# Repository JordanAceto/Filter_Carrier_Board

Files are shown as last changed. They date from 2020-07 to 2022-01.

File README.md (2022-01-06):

# PCB carrier board for VCF plug-in boards.



## [SCHEMATIC](https://github.com/JordanAceto/Filter_Carrier_Board/blob/master/main_pcb/construction_docs/filter_carrier_schematic.pdf)

### This PCB is designed to accomodate various filter boards documented elsewhere on my github page. Pots and jacks are mounted on this board, which can be affixed to a Eurorack panel. This way you can have one carrier board/panel, and swap in various VCF designs.

### A 12hp pcb panel is included in this repo as a cheap panel option.

### Since the panal and panel-mount components are typically a large expense in a synth module, this allows you to evaluate and experiment with different filter designs economically.

### Various plug-in boards have already been designed as part of a different project, and this seemed like an easy way to leverage an existing design in order to mess around with a Eurorack setup.

### Here is a link to the repository of the plug-in boards: [LINK](https://github.com/JordanAceto/VCF_plug_in_boards "filter plug-in boards")

## Status of the project:

Task | Status |
---------|--------------|
Schematic capture | &#9745;
PCB layout | &#9745;
Test build | &#9745;
Safe to order boards| &#9745;

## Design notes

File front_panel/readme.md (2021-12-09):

# Cheap and cheerful front panel option

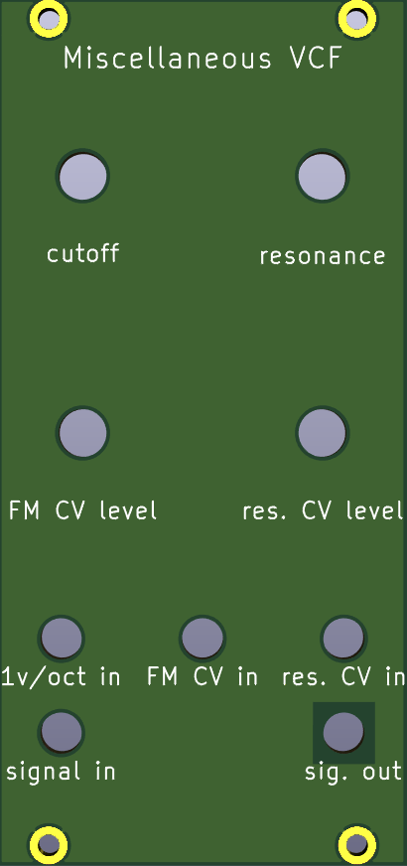
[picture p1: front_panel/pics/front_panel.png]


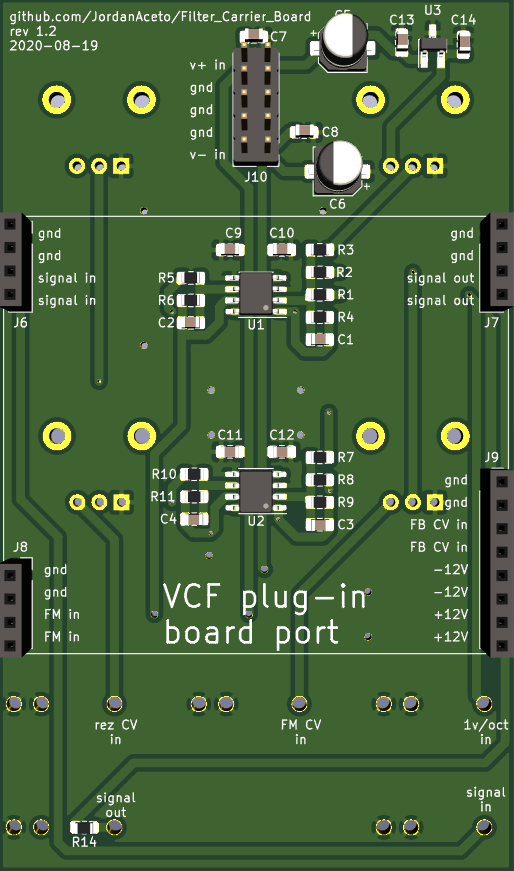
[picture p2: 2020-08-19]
main_pcb/pics/pcb_rear.png

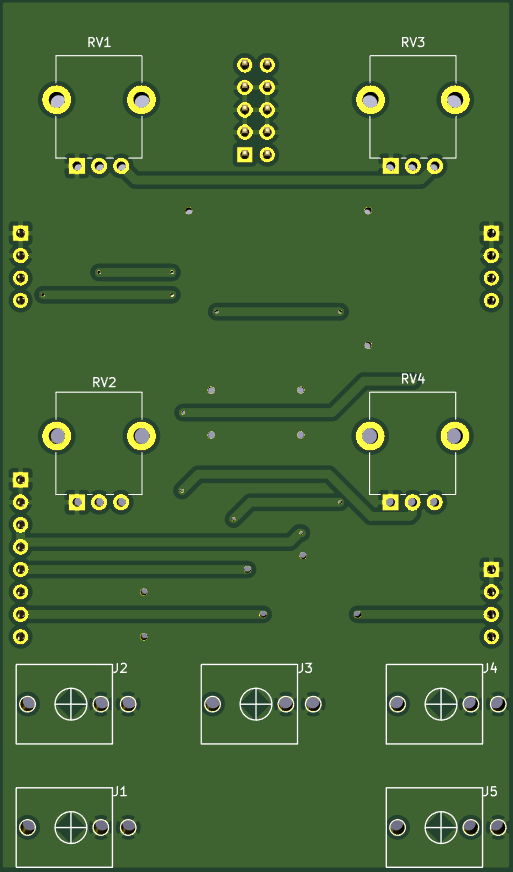
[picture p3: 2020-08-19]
main_pcb/pics/pcb_front.png

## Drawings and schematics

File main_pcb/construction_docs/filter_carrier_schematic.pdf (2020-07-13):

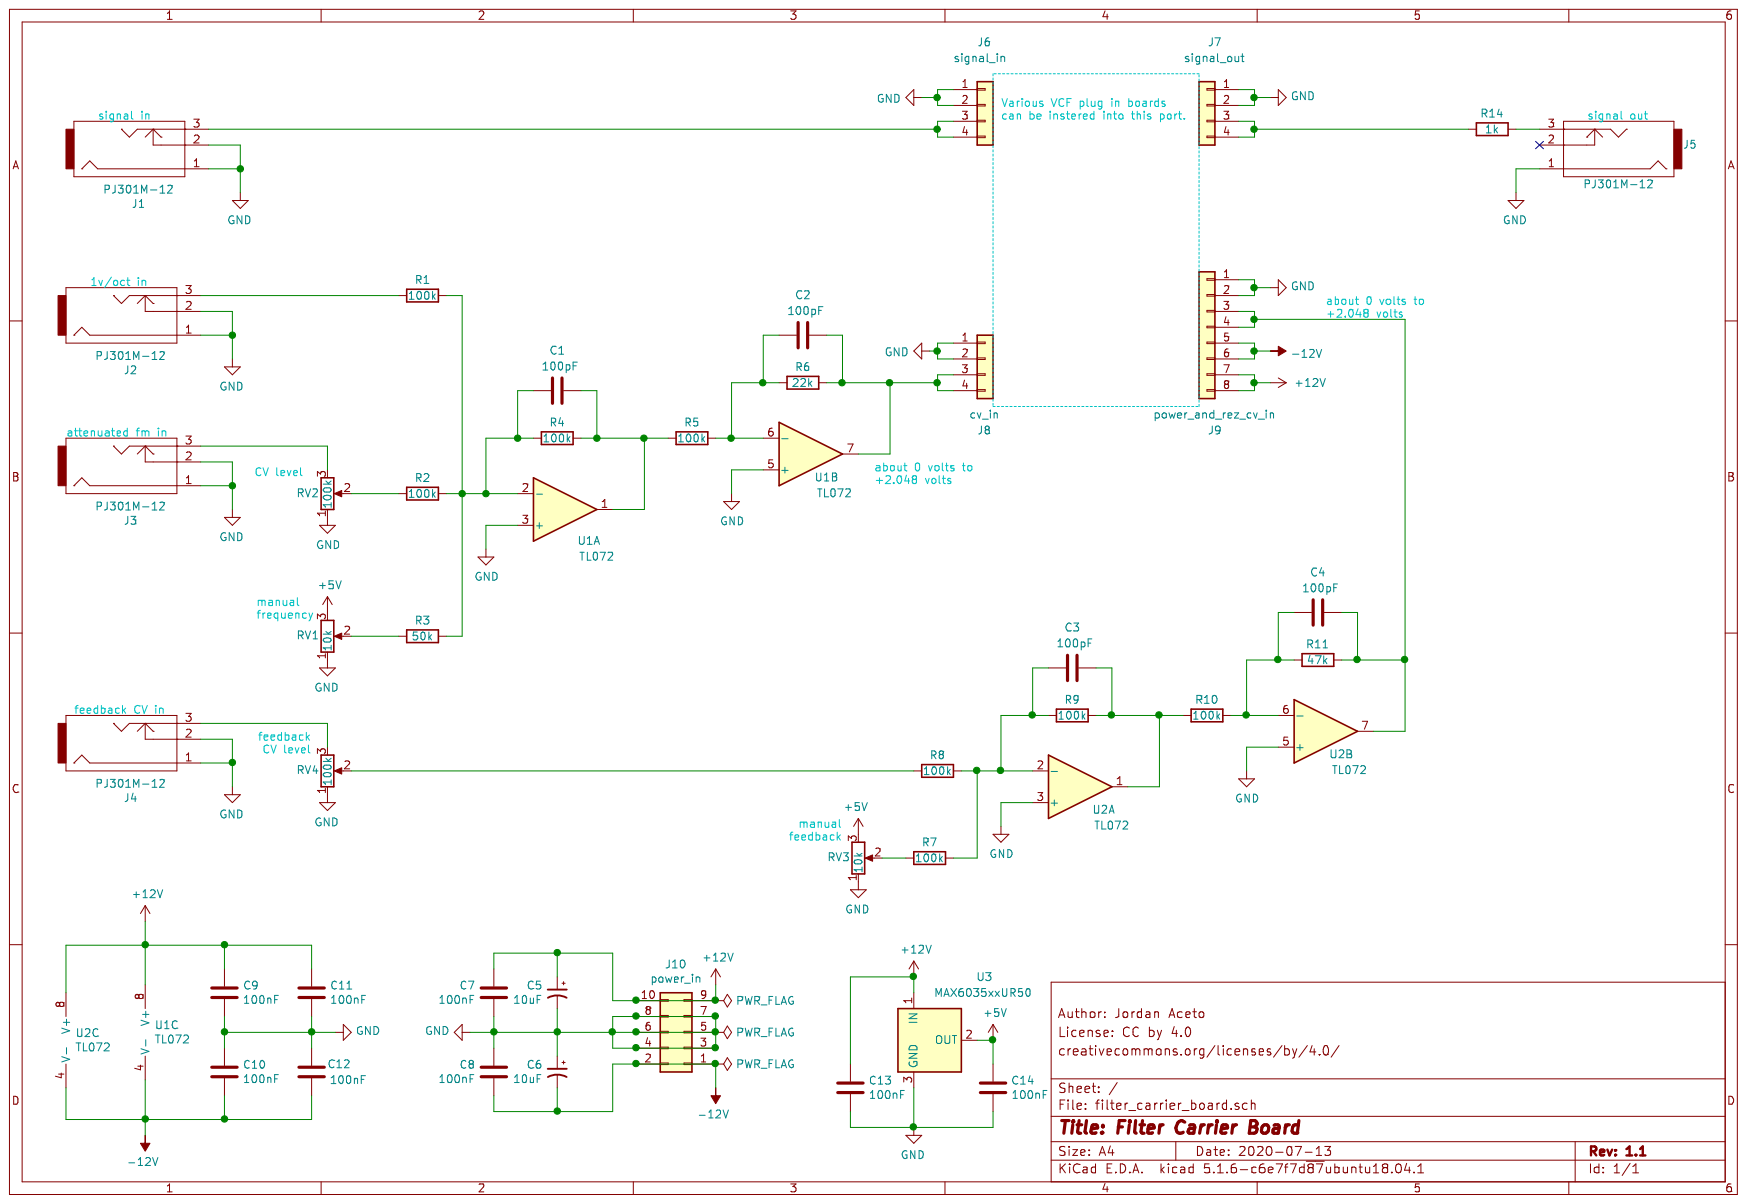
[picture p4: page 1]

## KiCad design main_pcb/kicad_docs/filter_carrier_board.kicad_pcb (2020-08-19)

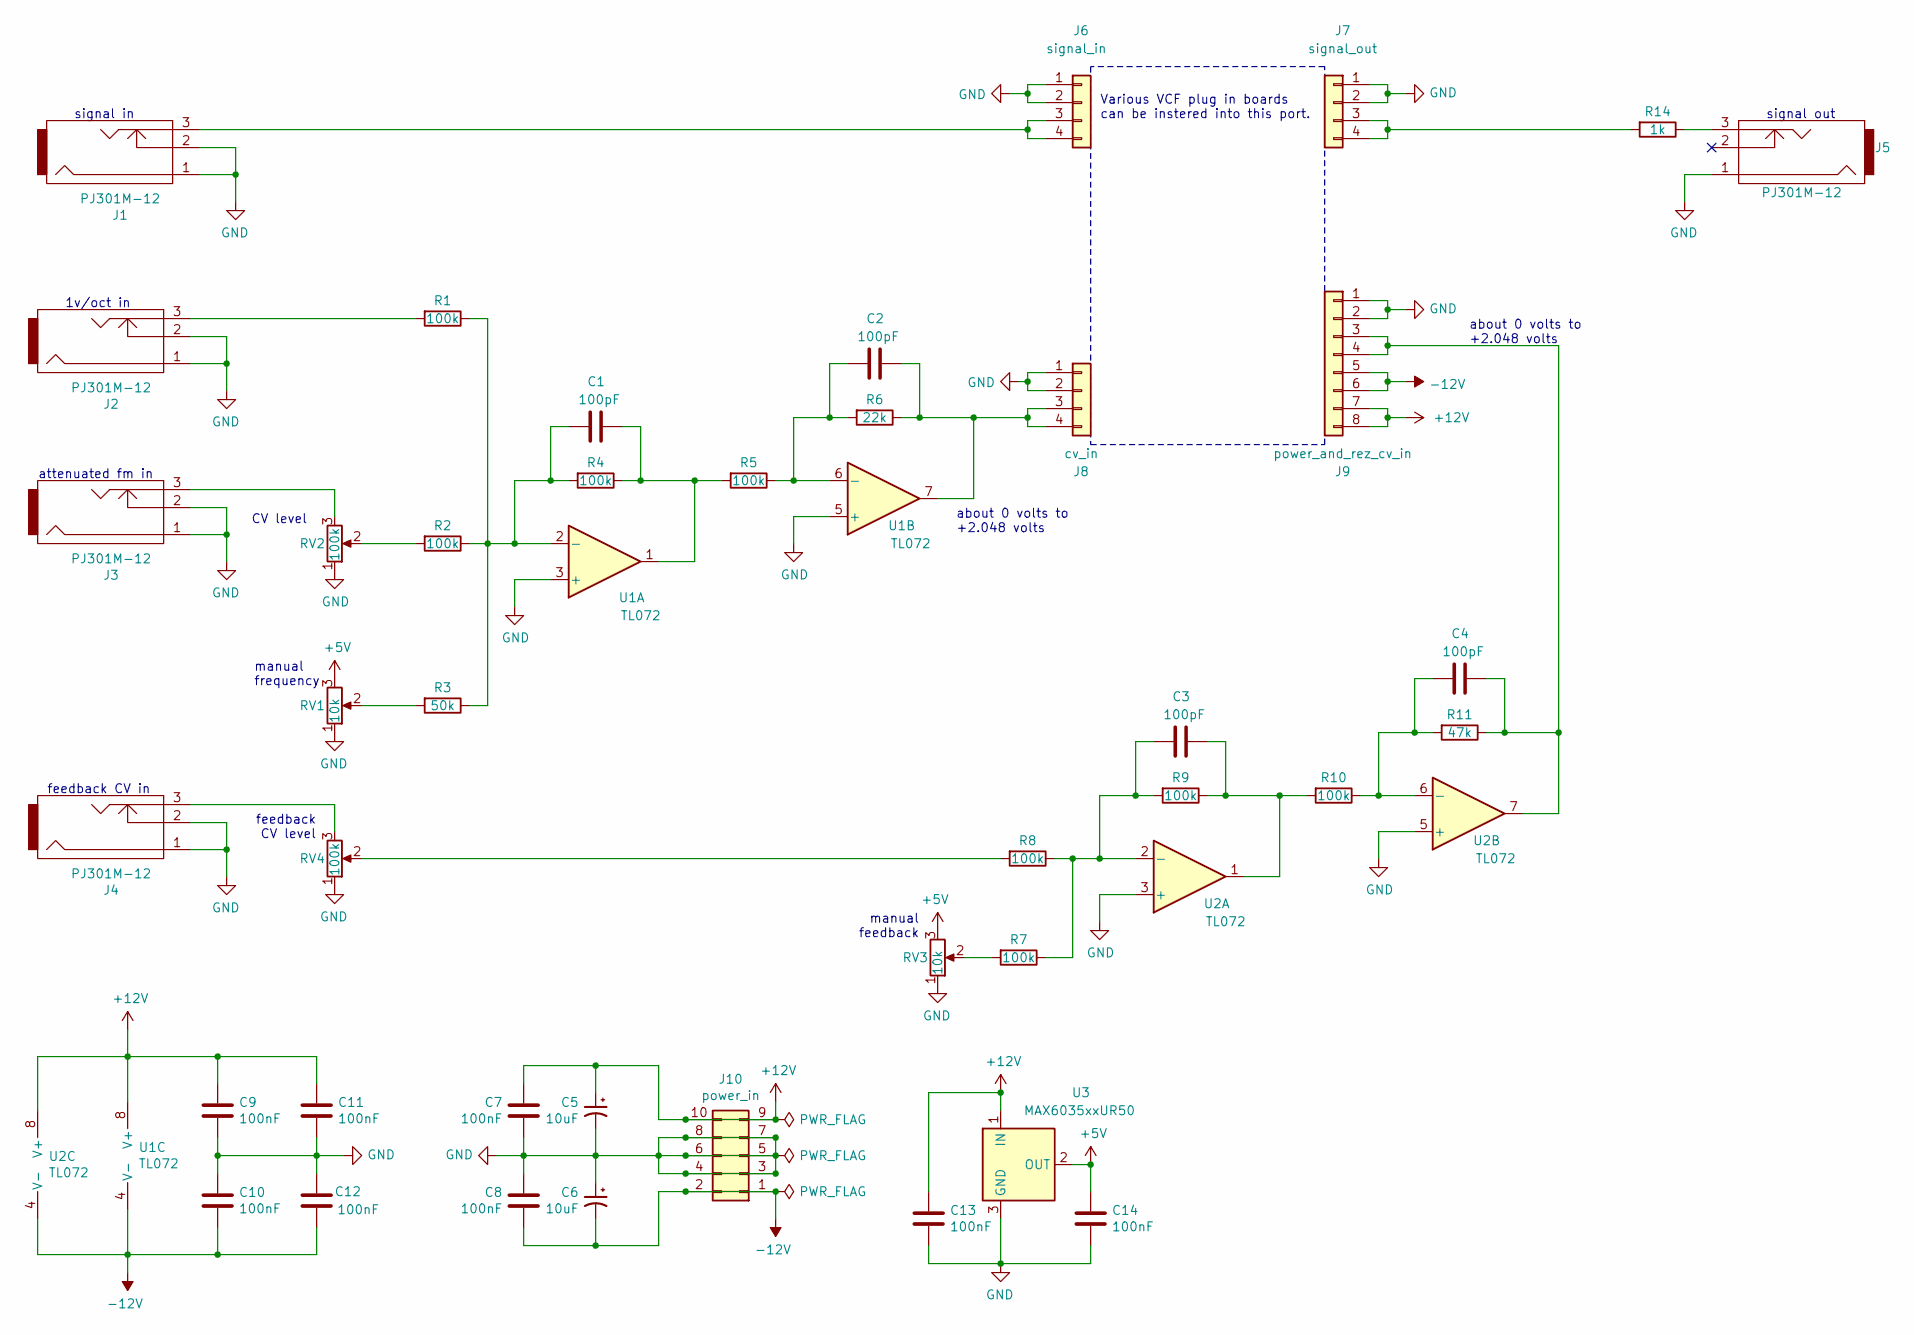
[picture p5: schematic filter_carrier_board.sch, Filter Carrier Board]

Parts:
C1, C2, C3, C4: 100pF; C_0805_2012Metric_Pad1.15x1.40mm_HandSolder
C5, C6: 10uF; CP_Elec_5x5.4
C7, C8, C9, C10, C11, C12, C13, C14: 100nF; C_0805_2012Metric_Pad1.15x1.40mm_HandSolder
J1, J2, J3, J4, J5: PJ301M-12
J6: signal_in; PinSocket_1x04_P2.54mm_Vertical
J7: signal_out; PinSocket_1x04_P2.54mm_Vertical
J8: cv_in; PinSocket_1x04_P2.54mm_Vertical
J9: power_and_rez_cv_in; PinSocket_1x08_P2.54mm_Vertical
J10: power_in; PinHeader_2x05_P2.54mm_Vertical
R1, R2, R4, R5, R7, R8, R9, R10: 100k; R_0805_2012Metric_Pad1.15x1.40mm_HandSolder
R3: 50k; R_0805_2012Metric_Pad1.15x1.40mm_HandSolder
R6: 22k; R_0805_2012Metric_Pad1.15x1.40mm_HandSolder
R11: 47k; R_0805_2012Metric_Pad1.15x1.40mm_HandSolder
R14: 1k; R_0805_2012Metric_Pad1.15x1.40mm_HandSolder
RV1, RV3: 10k; Potentiometer_Alpha_RD901F-40-00D_Single_Vertical_CircularH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
RV2, RV4: 100k; Potentiometer_Alpha_RD901F-40-00D_Single_Vertical_CircularH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
U1, U2: TL072; SOIC-8_3.9x4.9mm_P1.27mm
U3: MAX6035xxUR50; SOT-23_Handsoldering

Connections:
+5V: C14.1, RV1.3, RV3.3, U3.2 (OUT)
+12V: C5.1, C7.1, C9.1, C11.1, C13.1, J9.7, J9.8, J10.9, J10.10, U1.8 (V+), U2.8 (V+), U3.1 (IN)
-12V: C6.2, C8.2, C10.2, C12.2, J9.5, J9.6, J10.1, J10.2, U1.4 (V-), U2.4 (V-)
GND: C5.2, C6.1, C7.2, C8.1, C9.2, C10.1, C11.2, C12.1, C13.2, C14.2, J1.1, J1.2, J2.1, J2.2, J3.1, J3.2, J4.1, J4.2, J5.1, J6.1, J6.2, J7.1, J7.2, J8.1, J8.2, J9.1, J9.2, J10.3, J10.4, J10.5, J10.6, J10.7, J10.8, RV1.1, RV2.1, RV3.1, RV4.1, U1.3 (+), U1.5 (+), U2.3 (+), U2.5 (+), U3.3 (GND)
unnamed: C1.1, R4.1, R5.2, U1.1
unnamed: C1.2, R1.1, R2.1, R3.1, R4.2, U1.2 (-)
unnamed: C2.1, J8.3, J8.4, R6.1, U1.7
unnamed: C2.2, R5.1, R6.2, U1.6 (-)
unnamed: C3.1, R9.1, R10.2, U2.1
unnamed: C3.2, R7.1, R8.1, R9.2, U2.2 (-)
unnamed: C4.1, J9.3, J9.4, R11.1, U2.7
unnamed: C4.2, R10.1, R11.2, U2.6 (-)
unnamed: J1.3, J6.3, J6.4
unnamed: J2.3, R1.2
unnamed: J3.3, RV2.3
unnamed: J4.3, RV4.3
unnamed: J5.3, R14.1
unnamed: J7.3, J7.4, R14.2
unnamed: R2.2, RV2.2
unnamed: R3.2, RV1.2
unnamed: R7.2, RV3.2
unnamed: R8.2, RV4.2

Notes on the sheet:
manual frequency
1v/oct in
attenuated fm in
signal in
signal out
manual feedback
Various VCF plug in boards can be instered into this port.
feedback CV level
feedback CV in
CV level
about 0 volts to +2.048 volts

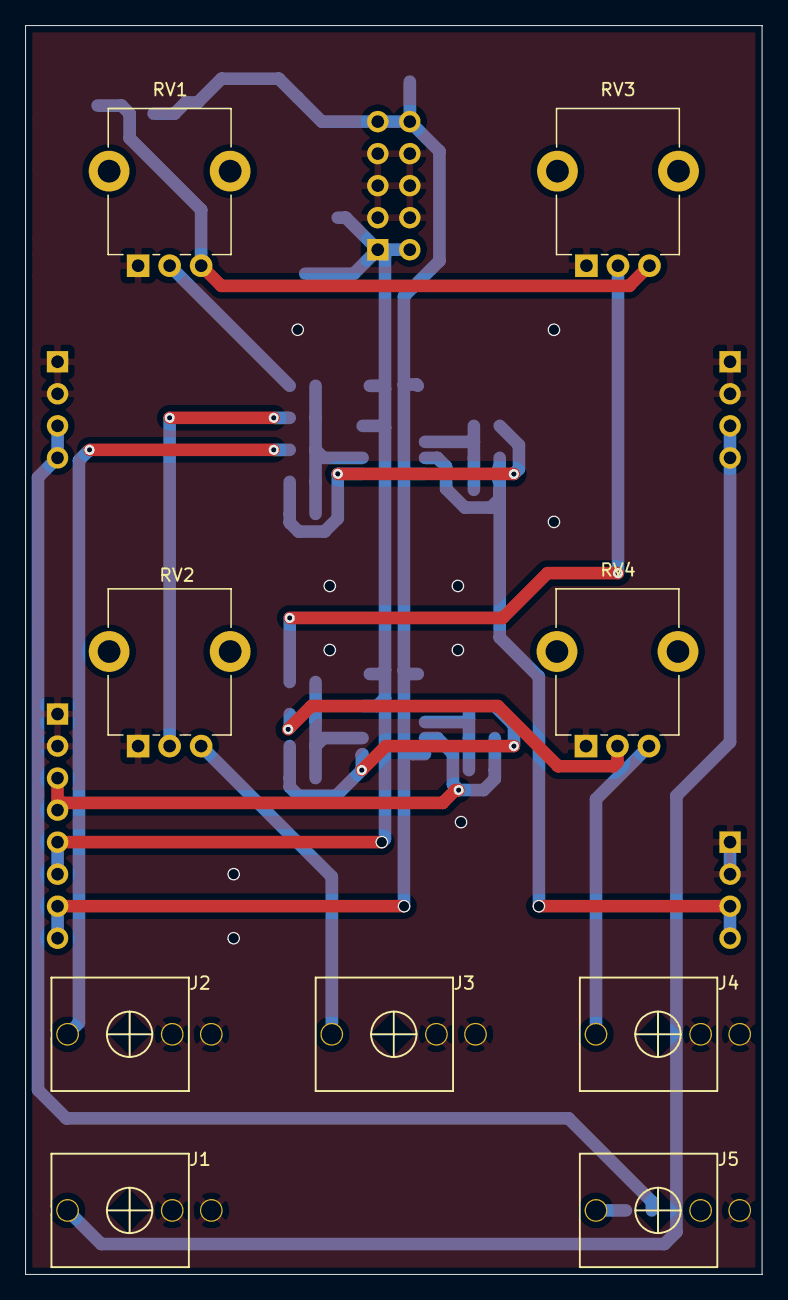
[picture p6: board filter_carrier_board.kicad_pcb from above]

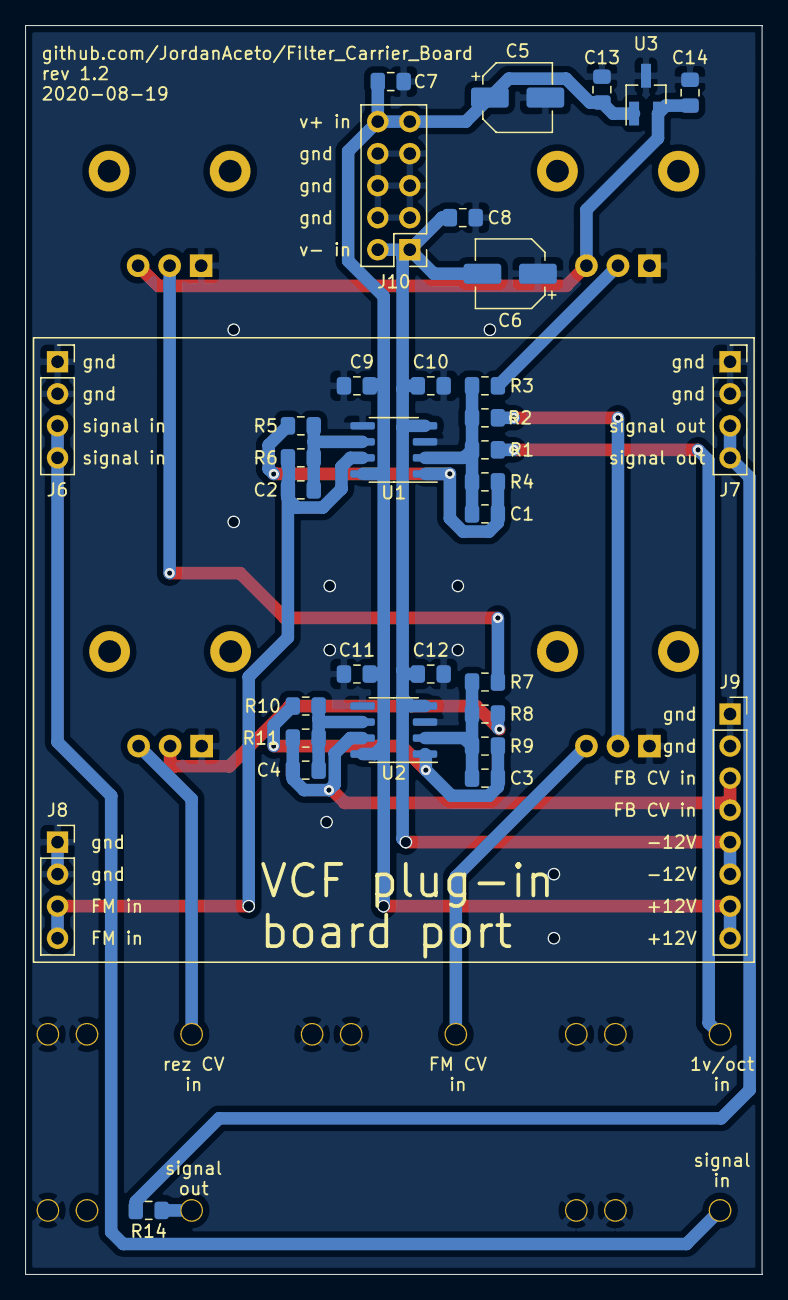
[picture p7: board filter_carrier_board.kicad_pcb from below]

Board: 2 copper layers, 58.4 x 99.1 mm, 43 parts (34 on the bottom side), 22 nets.

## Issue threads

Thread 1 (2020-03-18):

CV is inverted

JordanAceto, 2020-03-18:
I was a bonehead and made all the CV inputs inverted. The filter carrier boards expect control voltages in the range of 0v to +2.048v, with positive voltages corresponding to increasing filter cutoff frequency.

The whole CV input circuit is not well thought out.

To fix this issue: redesign the CV input summer/scaler. This will require changes in the schematic, pcb, pics, etc.

JordanAceto, 2020-03-18:
Done. Used the leftover opamp section for an input buffer for the audio signal.

Closed 2020-03-18.

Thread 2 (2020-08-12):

pcb spacing for plug-in board port is off by 0.1"

JordanAceto, 2020-08-12:
The vertical spacing for the plug-in board port is 0.1" too long, the plug-in boards will not fit, yikes.

Change the pcb so that it matches the correct plug-in board mechanical and electrical standard.

Do not order pcbs until this is fixed.

Note that with a couple of small trace cuts the bad pcb rev could work, by installing the signal_in and signal_out jacks off-by-one, if you're an idiot like me and bought boards like this.

Closed 2021-05-24.

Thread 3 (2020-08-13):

signal input and output traces are swapped

JordanAceto, 2020-08-13:
The signal input and signal output traces from the headers to the jacks are swapped, correct this before ordering boards.

Closed 2021-05-24.

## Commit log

2020-02-01 add schematic pdf
2020-02-23 route pcb traces away from pot footprints
    [filter_carrier_board.kicad_pcb]
2020-02-23 add github url to pcb silkscreen
    [filter_carrier_board.kicad_pcb]
2020-03-18 invert CV to proper polarity
    [filter_carrier_board.kicad_pcb, filter_carrier_board.sch]
2020-07-13 add VC resonance, big pcb change, add interactive BOM
    [filter_carrier_board.kicad_pcb, filter_carrier_board.sch]
2020-07-13 add front panel
    [front_panel.kicad_pcb, front_panel.sch]
2020-08-06 fix misplaced headers, update readme
    [filter_carrier_board-B_Cu.gbr, filter_carrier_board-B_Mask.gbr, filter_carrier_board-B_Paste.gbr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]
2020-08-12 add warning about bad pcb rev
2020-08-19 fix header spacing issue
    [filter_carrier_board-B_Cu.gbr, filter_carrier_board-B_Mask.gbr, filter_carrier_board-B_Paste.gbr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]
2021-12-09 regenerate output files
    [filter_carrier_board-B_Cu.gbr, filter_carrier_board-B_Mask.gbr, filter_carrier_board-B_Paste.gbr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]

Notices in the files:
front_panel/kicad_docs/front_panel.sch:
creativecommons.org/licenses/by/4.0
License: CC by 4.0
